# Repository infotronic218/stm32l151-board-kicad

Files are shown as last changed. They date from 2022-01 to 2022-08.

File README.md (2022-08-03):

# STM32L151 board design with KiCad 
The design files are available and free to use . The Bill of materials is in Excel format and be ordered from Mouser website. For Any project related question do not hesitate to message me thanks.
## Manufactured board view
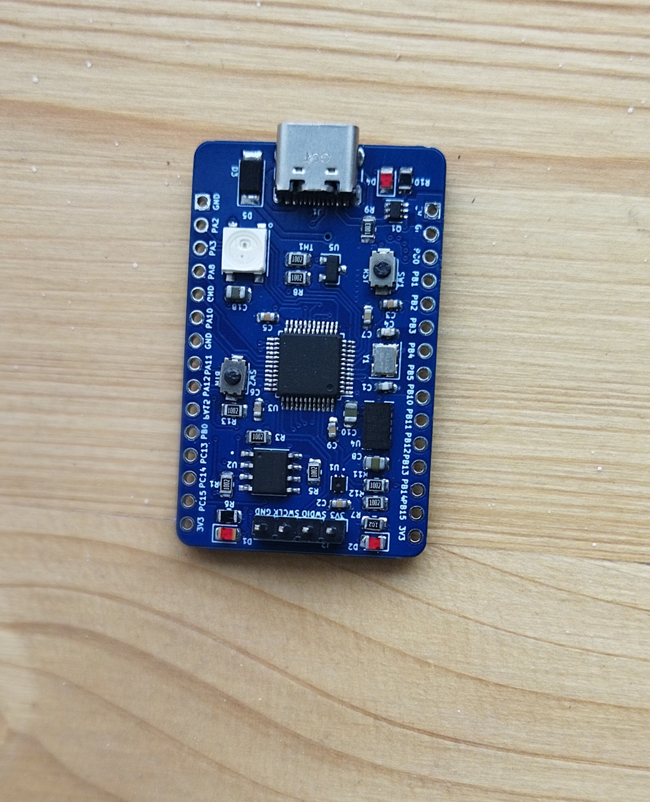
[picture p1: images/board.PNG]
JLPC Assembled Board


## Board Layout 3D View 
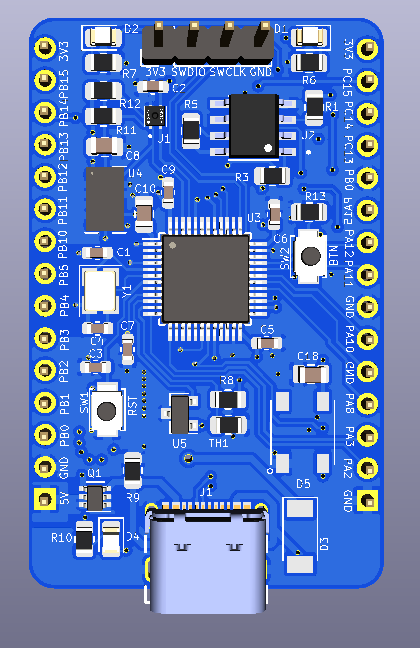
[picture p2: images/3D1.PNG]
3D View


## Board Layout View 2
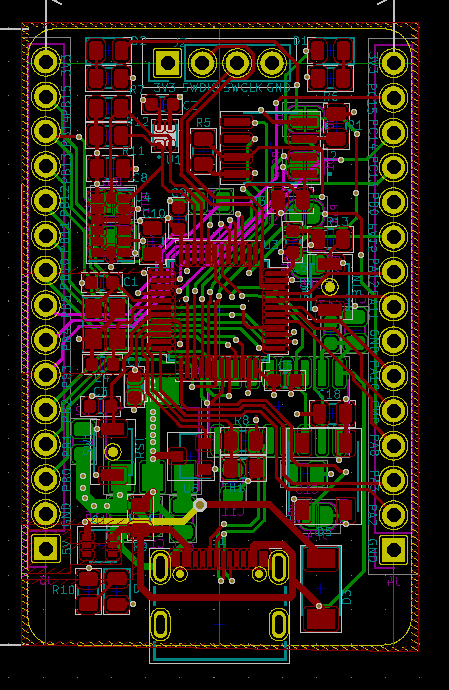
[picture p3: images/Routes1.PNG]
Routes


## Board Layout View 2
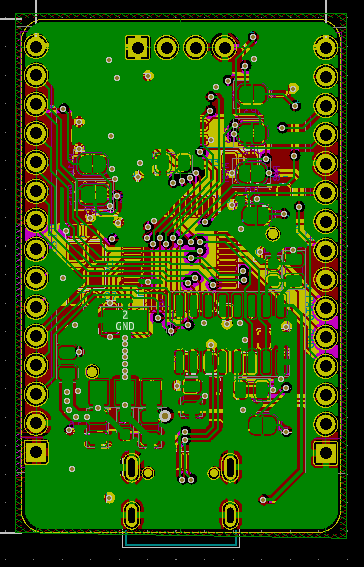
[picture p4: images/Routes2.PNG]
Routes


# List of sensors used in the design 
* Accelorometer 
* Analog Temperature sensor
* Digital Humidity and temperature sensor (I2C)
* External Flash memory (16Mbits)
* Digital RGB LED (IN-PI554FCH)
* Simple LED

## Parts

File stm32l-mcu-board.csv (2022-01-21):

Reference | Quantity | Value | Footprint | Datasheet | Description | MPN | Manufacturer | Mouser | DESCRIPTION | MANUFACTURER | MAXIMUM_PACKAGE_HEIGHT | PARTREV | STANDARD
C1 C4 | 2 | 12pF | Capacitor_SMD:C_0603_1608Metric | https://www.mouser.fr/ProductDetail/Kyocera-AVX/06035A120JAT2A?qs=aW6Wu37ixLRWqDfSP2xgeA%3D%3D | Multilayer Ceramic Capacitors MLCC - SMD/SMT 50V 12pF X7R 0603 5% AEC-Q200 | 06035A120JAT2A |  | 581-06035A120J
C8 C10 C11 C12 C14 C15 C16 C18 | 8 | 10uF | Capacitor_SMD:C_0805_2012Metric | https://www.mouser.fr/ProductDetail/KEMET/C0805C106K3PACTU | Multilayer Ceramic Capacitors MLCC - SMD/SMT 25V 10uF X5R 0805 10% | C0805C106K3PACTU |  | 80-C0805C106K3P
C2 C3 C5 C6 C7 C9 C13 C17 | 8 | 100nF | Capacitor_SMD:C_0603_1608Metric | https://www.mouser.fr/ProductDetail/KEMET/C0603C104K4RACTU | Multilayer Ceramic Capacitors MLCC - SMD/SMT 16V 0.1uF X7R 0603 10% | C0603C104K4RACTU |  | 80-C0603C104K4R
D3 | 1 | RB060LAM-40TFTR | Diode_SMD:D_SOD-128 | https://www.mouser.fr/ProductDetail/ROHM-Semiconductor/RB060LAM-40TFTR?qs=HXFqYaX1Q2z5zhuozTBNtg%3D%3D | Schottky Diodes & Rectifiers 40V VR 2A 0.45V VF PMDTM; SOD-128 | RB060LAM-40TFTR |  | 755-RB060LAM-40TFTR
D1 D2 D4 | 3 | LED | LED_SMD:LED_0805_2012Metric | https://www.mouser.fr/ProductDetail/Kingbright/AP2012HD?qs=sXafwHSx%252BU%252BY8L%2FmM05PMw%3D%3D | Standard LEDs - SMD RED DIFFUSED | AP2012HD | Kingbright | 604-AP2012HD | Standard LEDs - SMD RED DIFFUSED
D5 | 1 | LED-DIGITAL-IN-PI554FCH | 1KiCadLib:LED-DIGITAL-IN-PI554FCH | https://www.mouser.fr/ProductDetail/Inolux/IN-PI554FCH |  | IN-PI554FCH |  | 743-IN-PI554FCH
J1 | 1 | CON_USB_GCT_USB4105_REVA | 1KiCadLib:CON_USB_GCT_USB4105_REVA | https://www.mouser.fr/ProductDetail/GCT/USB4105-GF-A-060?qs=QNEnbhJQKvY2mocwNJzgfA%3D%3D | USB Connectors USB Type C, 2.0 SMT PCB Top Mnt .60mm | USB4105-GF-A-060 |  | 640-USB4105-GF-A-060 |  | GCT | 3.31 mm | 0.2 | Manufacturer Recommendations
J2 | 1 | PROG | Connector_PinHeader_2.54mm:PinHeader_1x04_P2.54mm_Vertical | ~ | ~ | ~ | ~ | ~
J3 J4 | 2 | PORT | Connector_PinHeader_2.54mm:PinHeader_1x15_P2.54mm_Vertical | ~ | ~ | ~ |  | ~
JP1 JP2 JP3 JP4 JP5 JP6 JP7 | 7 | Jumper_NC_Small | Jumper:SolderJumper-2_P1.3mm_Open_RoundedPad1.0x1.5mm | ~
Q1 | 1 | MIC94052YC6-TR | Package_TO_SOT_SMD:SOT-363_SC-70-6 | https://www.mouser.fr/ProductDetail/Microchip-Technology-Micrel/MIC94052YC6-TR | MOSFET 1.8V-rated PFET | MIC94052YC6-TR |  | 998-MIC94052YC6TR
R6 R7 R10 | 3 | 1.5K | Resistor_SMD:R_0805_2012Metric | https://www.mouser.fr/ProductDetail/Vishay-Dale/RCC08051K50FKEA | Thick Film Resistors - SMD 1/4W 1.5Kohms 1% 100ppm | RCC08051K50FKEA |  | 71-RCC08051K50FKEA | ~
R1 R2 R3 R4 R5 R8 R11 R12 R13 | 9 | 10K | Resistor_SMD:R_0805_2012Metric | https://www.mouser.fr/ProductDetail/Bourns/CR0805-FX-1002ELF?qs=tknLyCMIRbPr%252BDD0s0nG9g%3D%3D | Thick Film Resistors - SMD 10K 1% | CR0805-FX-1002ELF |  | 652-CR0805FX-1002ELF | ~
R9 | 1 | 100K | Resistor_SMD:R_0805_2012Metric | https://www.mouser.fr/ProductDetail/Bourns/CHP0805AFX-1003ELF?qs=BJlw7L4Cy79cbJ8BbmBQGw%3D%3D | Thick Film Resistors - SMD ResHighPowerA 0805 100k 1% 1/2W TC100 | CHP0805AFX-1003ELF |  | 652-CHP0805AFX1003EL | ~
SW1 SW2 | 2 | SW_Push | Button_Switch_SMD:SW_SPST_B3U-1000P-B | ~ | ~ | ~ |  | ~ | ~
TH1 | 1 | NTC 10K | Resistor_SMD:R_0805_2012Metric | https://www.mouser.fr/ProductDetail/ABRACON/ABNTC-0805-103J-3950F-T |  | ABNTC-0805-103J-3950F-T |  | 815-NTC805103J3950FT
U1 | 1 | IC-SENSOR-TEMP-HUM-SHT4X | 1KiCadLib:IC-SENSOR-TEMP-HUM-SHT4X | https://www.mouser.fr/ProductDetail/Sensirion/SHT40-AD1B-R3?qs=zW32dvEIR3sa7U6cFW6pBw%3D%3D | Board Mount Humidity Sensors RH/ T Sensor | SHT40-AD1B-R3 | Sensirion | 403-SHT40-AD1B-R3 | Board Mount Humidity Sensors RH/ T Sensor
U2 | 1 | W25Q16JVSNIQ | 1KiCadLib:IC-FLASH-16MB-W25Q16JVSNIQ | https://www.mouser.fr/ProductDetail/Winbond/W25Q16JVSNIQ | NOR Flash spiFlash, 3V, 16M-bit, 4Kb Uniform Sector | W25Q16JVSNIQ | Winbond | 454-W25Q16JVSNIQ | NOR Flash spiFlash, 3V, 16M-bit, 4Kb Uniform Sector
U3 | 1 | STM32L151CCTx | Package_QFP:LQFP-48_7x7mm_P0.5mm | http://www.st.com/st-web-ui/static/active/en/resource/technical/document/datasheet/DM00048356.pdf | ARM Microcontrollers - MCU Ultra Low M3 ARM 128 Kbytes 32 MHz | STM32L151CCT6 | Mfr.:STMicroelectronics | 511-STM32L151CCT6 | ARM Microcontrollers - MCU Ultra Low M3 ARM 128 Kbytes 32 MHz
U4 | 1 | ADXL343 | Package_LGA:LGA-14_3x5mm_P0.8mm_LayoutBorder1x6y | https://www.mouser.fr/ProductDetail/Analog-Devices/ADXL343BCCZ-RL7?qs=WIvQP4zGaniOvQtxs%252BDc3A%3D%3D |  | ADXL343BCCZ-RL7 |  | 584-ADXL343BCCZ-R7
U5 | 1 | MCP9701T-E/TT | Package_TO_SOT_SMD:SOT-23 | https://www.mouser.fr/ProductDetail/Microchip-Technology/MCP9701T-E-TT |  | MCP9701T-E/TT |  | 579-MCP9701T-E/TT
U6 | 1 | CH340C | Package_SO:SOIC-16_3.9x9.9mm_P1.27mm | https://datasheet.lcsc.com/szlcsc/Jiangsu-Qin-Heng-CH340C_C84681.pdf | ~ | ~ |  | ~ | ~
U7 | 1 | TC1264-3.3VDBTR | Package_TO_SOT_SMD:SOT-223-3_TabPin2 | https://www.mouser.fr/ProductDetail/Microchip-Technology/TC1264-33VDBTR?qs=EkZBwCRGcSs72PT5fOeaFg%3D%3D | LDO Voltage Regulators 800mA Fixed Output | TC1264-3.3VDBTR | Microchip Technology | 579-TC1264-3.3VDBTR
Y1 | 1 | 16MHz | Crystal:Crystal_SMD_3225-4Pin_3.2x2.5mm | https://www.mouser.fr/ProductDetail/Kyocera-AVX/CX3225SB16000E0EGFCC?qs=a4BXICGgSn8pxVCU1V0Bdw%3D%3D | Crystals AEC-Q200 16000kHz 9pF 3.2x2.5mm | CX3225SB16000E0EGFCC | Kyocera AVX | 581-CX3225SB16000EGF

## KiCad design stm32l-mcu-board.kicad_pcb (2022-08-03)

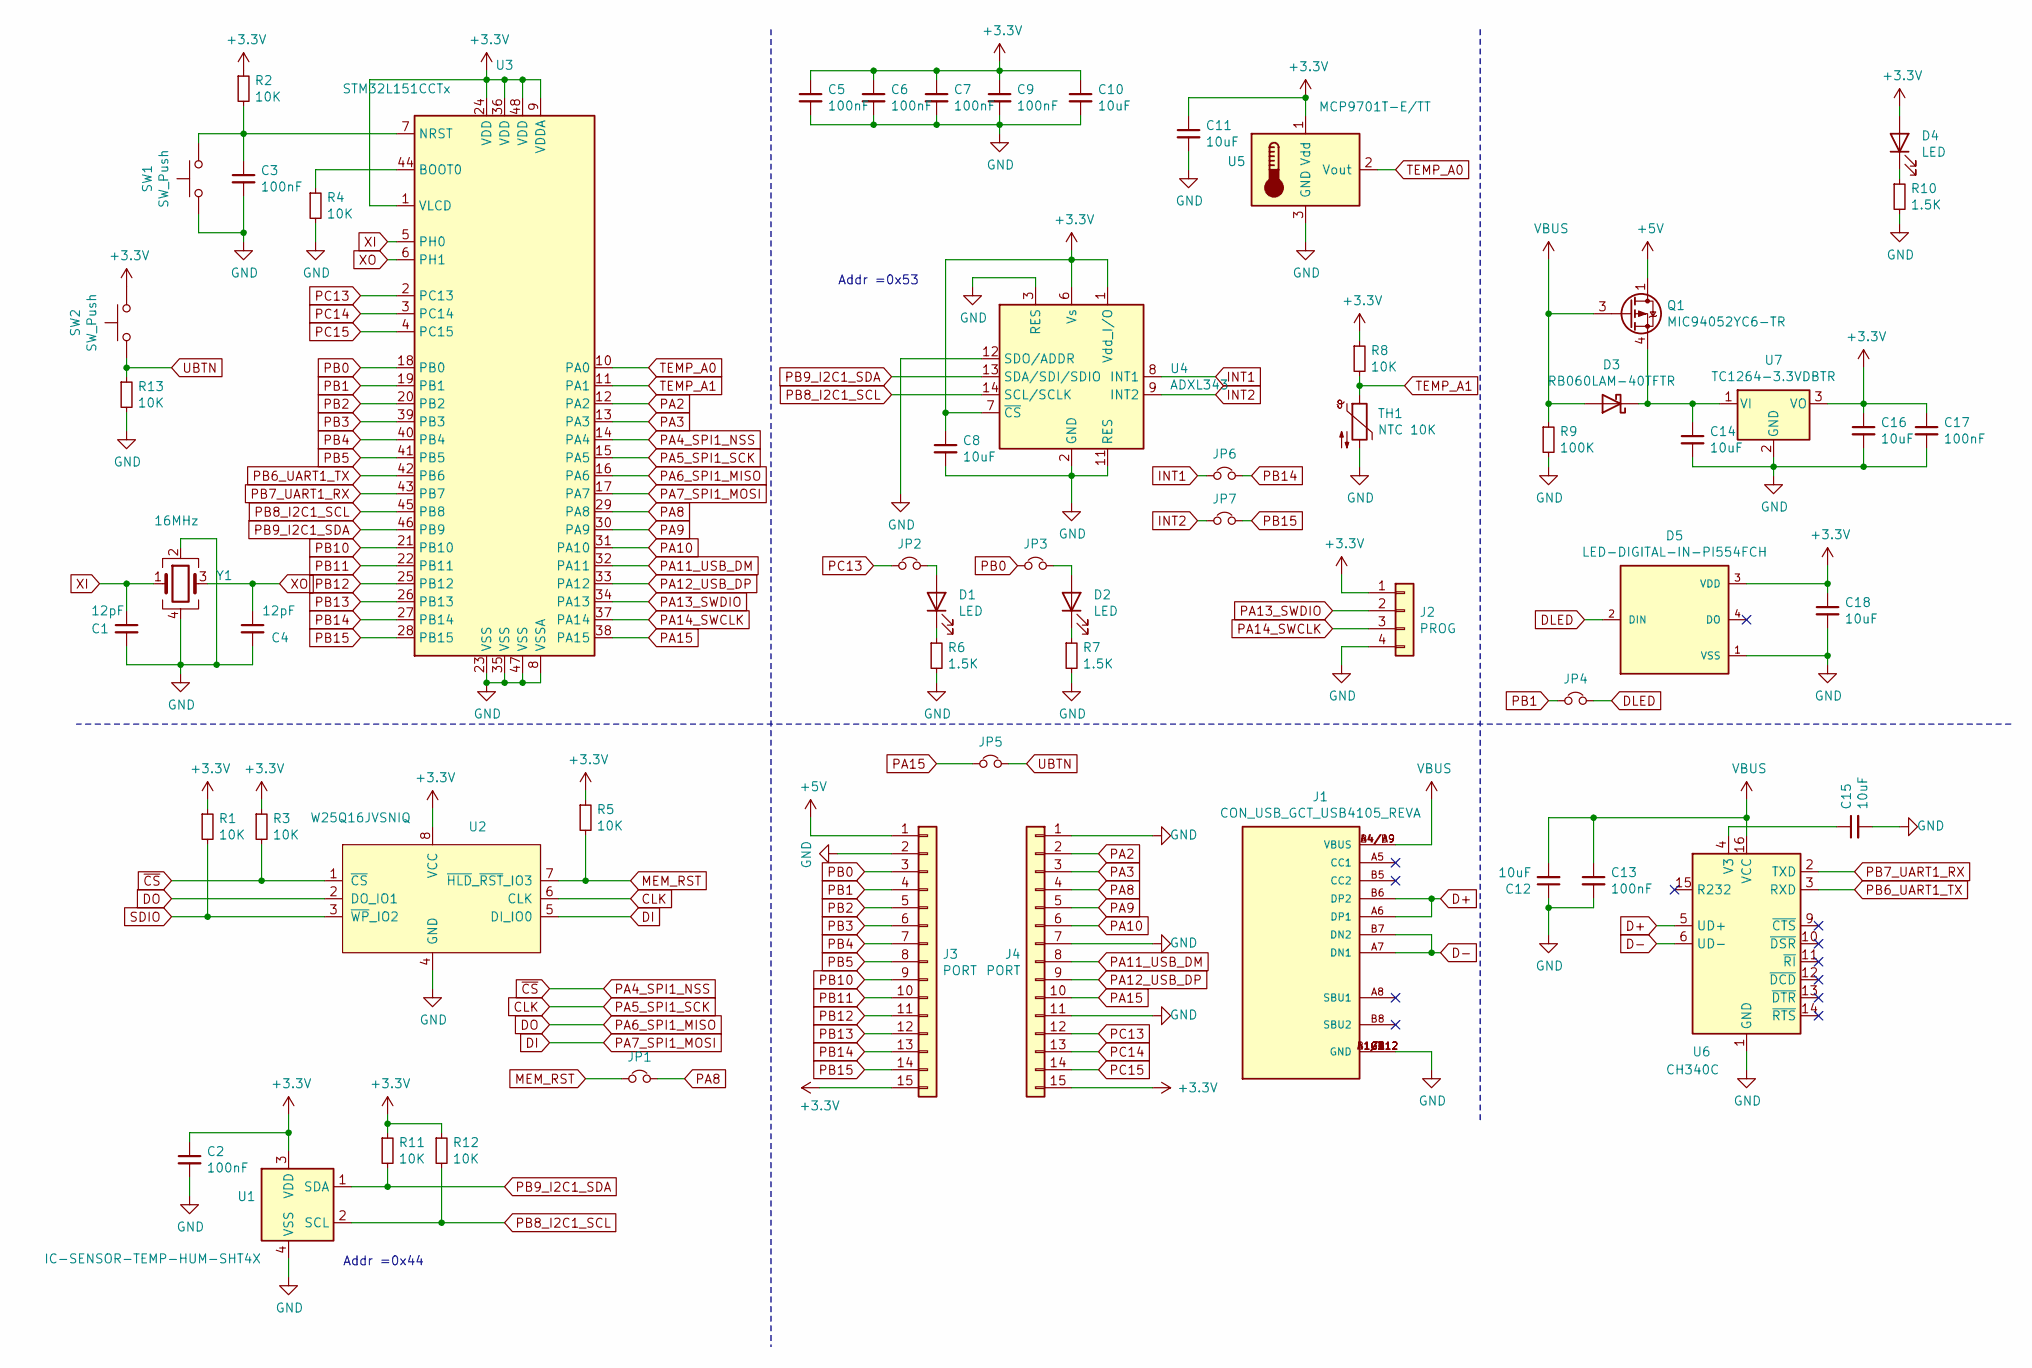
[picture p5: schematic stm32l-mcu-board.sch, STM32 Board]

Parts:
C1, C4: 12pF; C_0603_1608Metric; MPN 06035A120JAT2A; Mouser 581-06035A120J
C2, C3, C5, C6, C7, C9, C13, C17: 100nF; C_0603_1608Metric; MPN C0603C104K4RACTU; Mouser 80-C0603C104K4R
C8, C10, C11, C12, C14, C15, C16, C18: 10uF; C_0805_2012Metric; MPN C0805C106K3PACTU; Mouser 80-C0805C106K3P
D1, D2, D4: LED; LED_0805_2012Metric; MPN AP2012HD; Mouser 604-AP2012HD
D3: RB060LAM-40TFTR; D_SOD-128; MPN RB060LAM-40TFTR; Mouser 755-RB060LAM-40TFTR
D5: LED-DIGITAL-IN-PI554FCH; MPN IN-PI554FCH; Mouser 743-IN-PI554FCH
J1: CON_USB_GCT_USB4105_REVA; PARTREV 0.2; Mouser 640-USB4105-GF-A-060
J2: PROG; PinHeader_1x04_P2.54mm_Vertical
J3, J4: PORT; PinHeader_1x15_P2.54mm_Vertical
JP1, JP2, JP3, JP4, JP5, JP6, JP7: Jumper_NC_Small; SolderJumper-2_P1.3mm_Open_RoundedPad1.0x1.5mm
Q1: MIC94052YC6-TR; SOT-363_SC-70-6; MPN MIC94052YC6-TR; Mouser 998-MIC94052YC6TR
R1, R2, R3, R4, R5, R8, R11, R12, R13: 10K; R_0805_2012Metric; MPN CR0805-FX-1002ELF; Mouser 652-CR0805FX-1002ELF
R6, R7, R10: 1.5K; R_0805_2012Metric; MPN RCC08051K50FKEA; Mouser 71-RCC08051K50FKEA
R9: 100K; R_0805_2012Metric; MPN CHP0805AFX-1003ELF; Mouser 652-CHP0805AFX1003EL
SW1, SW2: SW_Push; SW_SPST_B3U-1000P-B
TH1: NTC 10K; R_0805_2012Metric; MPN ABNTC-0805-103J-3950F-T; Mouser 815-NTC805103J3950FT
U1: IC-SENSOR-TEMP-HUM-SHT4X; MPN SHT40-AD1B-R3; Mouser 403-SHT40-AD1B-R3
U2: W25Q16JVSNIQ; IC-FLASH-16MB-W25Q16JVSNIQ; MPN W25Q16JVSNIQ; Mouser 454-W25Q16JVSNIQ
U3: STM32L151CCTx; LQFP-48_7x7mm_P0.5mm; MPN STM32L151CCT6; Mouser 511-STM32L151CCT6
U4: ADXL343; LGA-14_3x5mm_P0.8mm_LayoutBorder1x6y; MPN ADXL343BCCZ-RL7; Mouser 584-ADXL343BCCZ-R7
U5: MCP9701T-E/TT; SOT-23; MPN MCP9701T-E/TT; Mouser 579-MCP9701T-E/TT
U6: CH340C; SOIC-16_3.9x9.9mm_P1.27mm
U7: TC1264-3.3VDBTR; SOT-223-3_TabPin2; MPN TC1264-3.3VDBTR; Mouser 579-TC1264-3.3VDBTR
Y1: 16MHz; Crystal_SMD_3225-4Pin_3.2x2.5mm; MPN CX3225SB16000E0EGFCC; Mouser 581-CX3225SB16000EGF

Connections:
+3V3: C2.1, C5.1, C6.1, C7.1, C8.1, C9.1, C10.1, C11.1, C16.1, C17.1, C18.1, D4.2 (A), D5.3 (VDD), J2.1, J3.15, J4.15, R1.1, R2.1, R3.1, R5.1, R8.1, R11.1, R12.1, SW2.2, U1.3 (VDD), U2.8 (VCC), U3.1 (VLCD), U3.9 (VDDA), U3.24 (VDD), U3.36 (VDD), U3.48 (VDD), U4.1 (Vdd_I/O), U4.6 (Vs), U4.7 (~CS), U5.1 (Vdd), U7.3 (VO)
+5V: J3.1, Q1.1 (D), Q1.2 (S), Q1.5 (D), Q1.6 (D)
CLK: U2.6 (CLK), U3.15 (PA5)
D+: J1.A6 (DP1), J1.B6 (DP2), U6.5 (UD+)
D-: J1.A7 (DN1), J1.B7 (DN2), U6.6 (UD-)
DI: U2.5 (DI_IO0), U3.17 (PA7)
DLED: D5.2 (DIN), JP4.2
DO: U2.2 (DO_IO1), U3.16 (PA6)
GND: C1.2, C2.2, C3.2, C4.2, C5.2, C6.2, C7.2, C8.2, C9.2, C10.2, C11.2, C12.1, C13.2, C14.2, C15.2, C16.2, C17.2, C18.2, D5.1 (VSS), J1.A1/B12 (GND), J1.B1/A12 (GND), J1.G1 (GND), J1.G2 (GND), J1.G3 (GND), J1.G4 (GND), J2.4, J3.2, J4.1, J4.7, J4.11, R4.2, R6.2, R7.2, R9.2, R10.2, R13.2, SW1.1, TH1.2, U1.4 (VSS), U2.4 (GND), U3.8 (VSSA), U3.23 (VSS), U3.35 (VSS), U3.47 (VSS), U4.2 (GND), U4.3 (RES), U4.4 (GND), U4.5 (GND), U4.11 (RES), U4.12 (SDO/ADDR), U5.3 (GND), U6.1 (GND), U7.2 (GND), Y1.2, Y1.4
INT1: JP6.1, U4.8 (INT1)
INT2: JP7.1, U4.9 (INT2)
MEM_RST: JP1.1, R5.2, U2.7 (~HLD~_~RST~_IO3)
unnamed: C3.1, R2.2, SW1.2, U3.7 (NRST)
unnamed: C14.1, D3.1 (K), Q1.4 (S), U7.1 (VI)
unnamed: C15.1, U6.4 (V3)
unnamed: D1.1 (K), R6.1
unnamed: D1.2 (A), JP2.2
unnamed: D2.1 (K), R7.1
unnamed: D2.2 (A), JP3.2
unnamed: D4.1 (K), R10.1
unnamed: R4.1, U3.44 (BOOT0)
PA2: J4.2, U3.12 (PA2)
PA3: J4.3, U3.13 (PA3)
PA4_SPI1_NSS: R3.2, U2.1 (~CS), U3.14 (PA4)
PA8: J4.4, JP1.2, U3.29 (PA8)
PA9: J4.5, U3.30 (PA9)
PA10: J4.6, U3.31 (PA10)
PA11_USB_DM: J4.8, U3.32 (PA11)
PA12_USB_DP: J4.9, U3.33 (PA12)
PA13_SWDIO: J2.2, U3.34 (PA13)
PA14_SWCLK: J2.3, U3.37 (PA14)
PA15: J4.10, JP5.1, U3.38 (PA15)
PB0: J3.3, JP3.1, U3.18 (PB0)
PB1: J3.4, JP4.1, U3.19 (PB1)
PB2: J3.5, U3.20 (PB2)
PB3: J3.6, U3.39 (PB3)
PB4: J3.7, U3.40 (PB4)
PB5: J3.8, U3.41 (PB5)
PB6_UART1_TX: U3.42 (PB6), U6.3 (RXD)
PB7_UART1_RX: U3.43 (PB7), U6.2 (TXD)
PB8_I2C1_SCL: R12.2, U1.2 (SCL), U3.45 (PB8), U4.14 (SCL/SCLK)
PB9_I2C1_SDA: R11.2, U1.1 (SDA), U3.46 (PB9), U4.13 (SDA/SDI/SDIO)
PB10: J3.9, U3.21 (PB10)
PB11: J3.10, U3.22 (PB11)
PB12: J3.11, U3.25 (PB12)
PB13: J3.12, U3.26 (PB13)
PB14: J3.13, JP6.2, U3.27 (PB14)
PB15: J3.14, JP7.2, U3.28 (PB15)
PC13: J4.12, JP2.1, U3.2 (PC13)
PC14: J4.13, U3.3 (PC14)
PC15: J4.14, U3.4 (PC15)
SDIO: R1.2, U2.3 (~WP~_IO2)
TEMP_A0: U3.10 (PA0), U5.2 (Vout)
TEMP_A1: R8.2, TH1.1, U3.11 (PA1)
UBTN: JP5.2, R13.1, SW2.1
VBUS: C12.2, C13.1, D3.2 (A), J1.A4/B9 (VBUS), J1.B4/A9 (VBUS), Q1.3 (G), R9.1, U6.16 (VCC)
XI: C1.1, U3.5 (PH0), Y1.1
XO: C4.1, U3.6 (PH1), Y1.3

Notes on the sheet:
Addr =0x44
Addr =0x53

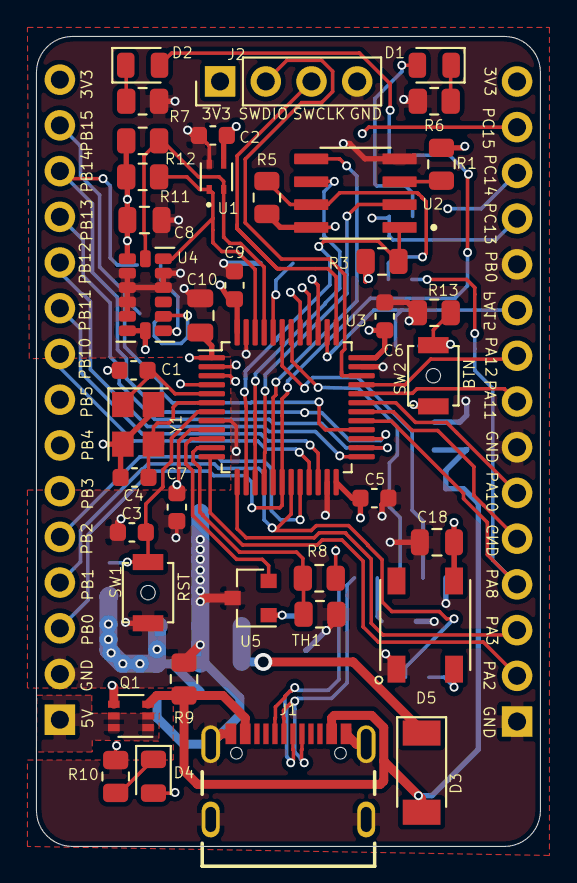
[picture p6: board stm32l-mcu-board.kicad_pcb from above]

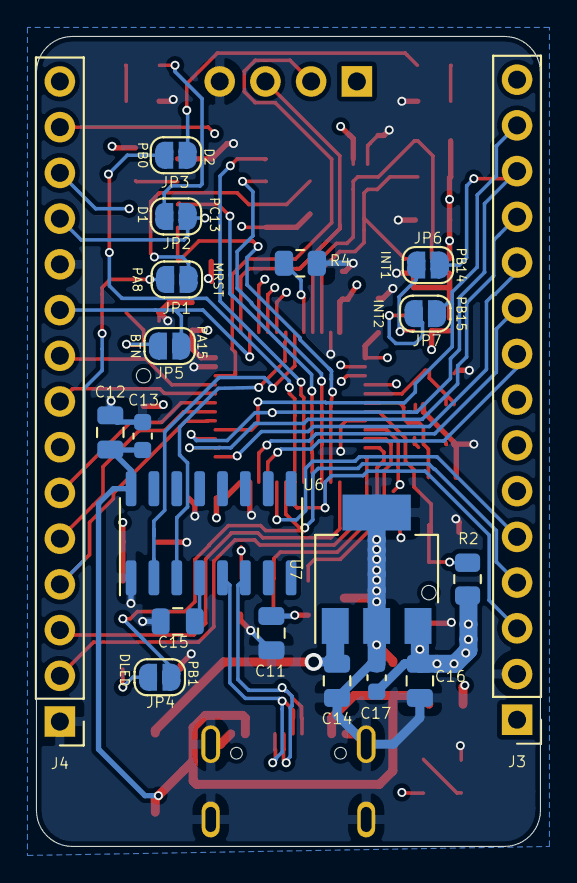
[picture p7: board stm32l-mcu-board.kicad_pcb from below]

Board: 4 copper layers, 28.0 x 45.0 mm, 59 parts (20 on the bottom side), 58 nets.

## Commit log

2022-01-21 Uploding the project to git
    [stm32l-mcu-board-B_Cu.gbr, stm32l-mcu-board-B_Mask.gbr, stm32l-mcu-board-B_Paste.gbr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]
2022-08-03 Update the Flash memory circuit
    [stm32l-mcu-board-B_Cu.gbr, stm32l-mcu-board-B_Mask.gbr, stm32l-mcu-board-B_Paste.gbr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]
